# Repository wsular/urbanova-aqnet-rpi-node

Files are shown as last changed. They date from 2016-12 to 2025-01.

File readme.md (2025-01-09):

# Air Quality Network Sensor

## Urbanova

Source code and documentation for an experimental air quality sensor node based
on the Raspberry Pi series and low-cost retail sensors. Measurements are made 
every 10 seconds and recorded to local storage in tab-separated (TSV) files. 
Data are also exported to temporary files for integration with 
[RPi Monitor](https://rpi-experiences.blogspot.com) and `scp`-based scraping 
tools (e.g. the [Itron](https://www.itron.com/na/) Cloud service agent). 

This project is currently being adapted to support multiple platforms, with 
multiple sensor configurations:

| | Original prototype | Next generation |
|:---|:---:|:---:|
| Git branch name | `pi0-usb` | `master` |
| Base platform | [Pi Zero][1] | [Pi 3][2] |
| Operating system | Raspbian Lite (Jessie) | Raspbian Lite (Stretch) |
| Data communications | USB network interface  | Wi-Fi or cellular (2/3G) ([FONA 808][3]) |
| Clock source | RTC ([DS3231][4]) | GPS ([Ultimate GPS][5]) |
| Analog-to-digital converter | n/a | ? (2ch, diff: [ADS1115][10]) |
|-|-|-|-|
| Carbon dioxide conc. (CO<sub>2</sub>) | &check; ([K30][6]) | &check; ([K30][6]) |
| Particulate conc. (PM<sub>1/2.5/10</sub>) | &check; ([OPC-N2][7]) | &check; ([OPC-N2][7])  |
| Ozone conc. (O<sub>3</sub>) | &cross; | ? ([OX-B431][8]) |
| Nitrogen dioxide conc. (NO<sub>2</sub>) | &cross; | ? ([NO2-B43F][9]) |
| Ambient air temp. | &check; ([HTU21DF][11]) | &check; ([BME280][13]) |
| Ambient relative humidity | &check; ([HTU21DF][11]) | &check; ([BME280][13]) |
| Barometric pressure | &check; ([BMP280][12])  | &check; ([BME280][13]) |
| Enclosure (internal) temp. | &check; ([BMP280][12])  | &cross; |
| Location (GPS coordinates) | &cross; | &check; GPS ([Ultimate GPS][5]) |

  [1]: https://www.raspberrypi.org/products/raspberry-pi-zero/
  [2]: https://www.raspberrypi.org/products/raspberry-pi-zero/
  [3]: https://www.adafruit.com/product/2542 "FONA 808"
  [4]: https://www.adafruit.com/product/3013 "DS3231 breakout"
  [5]: https://www.adafruit.com/product/746 "Ultimate GPS"
  [6]: http://senseair.senseair.com/products/oem-modules/k30/ "K30"
  [7]: http://www.alphasense.com/index.php/products/optical-particle-counter/ "OPC-N2"
  [8]: http://www.alphasense.com/index.php/products/ozone-2/
  [9]: http://www.alphasense.com/index.php/products/nitrogen-dioxide-2/
  [10]: https://www.adafruit.com/product/1085 "ADS1115"
  [11]: https://www.adafruit.com/product/1899 "HTU21DF breakout"
  [12]: https://www.adafruit.com/product/2651 "BMP280 breakout"
  [13]: https://www.adafruit.com/product/2652 "BME280 breakout"

### Documentation

* [Assembly notes](doc/hardware.md)
* [Initial setup](doc/software.md)
* [Integration with Itron Cloud](doc/itron.md)

Also, a relevant excerpt from optical particle counter user manual:

> "The accepted international standard definitions of particle mass loadings in
> the air are PM1, PM2.5 and PM10.  These definitions relate to the mass and 
> size of particles that would be inhaled by a typical adult. So, for example,
> PM2.5 is defined as ‘particles which pass through a size-selective inlet with
> a 50% efficiency cut-off at 2.5 μm aerodynamic diameter’.  The 50% cut-off 
> indicates that a proportion of particles of larger than 2.5 μm will be 
> included in PM2.5, the proportion decreasing withincreasing particle size, in
> this case out to approximately 10 μm particles."

### Testing

A few test data sets are available [here](testing/). You can view example code
in the Jupyter notebook "[Validation Testing](testing/Validation%20Testing.ipynb)" 
directly in Github, or to see/interact with the Bokeh plots too, open locally
with Jupyter or [render it](http://nbviewer.jupyter.org/github/wsular/urbanova-aqnet-rpi-node/blob/master/testing/Validation%20Testing.ipynb)
using nbviewer.jupyter.org. 

* Bench test (Dec 4-5, 2016)
* Roof test #1 (Dec 5-6, 2016)
* Roof test #2 (Dec 14, 2016 - Jan 9, 2017)

### License

This work licensed under [The MIT License](http://opensource.org/licenses/mit-license.html).

### References

* Alphasense. *Alphasense User Manual OPC-N2 Optical Particle Counter.*
  Revision Apr 2015. Online: 
  <http://web.archive.org/web/20161203001923/http://staging1.unep.org/uneplive/media/docs/air_quality/aqm_document_v1/Blue%20Print/Components/Microcomputer%20and%20sens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>

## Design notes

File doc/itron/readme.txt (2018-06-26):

# Integration with the Itron Cloud

### Querying for data in real time

The Itron system controller generates and loads an ssh key onto the downstream
air quality sensor node computer during initial device setup. Subsequently,
the Itron controller issues remote shell commands (i.e. `cat`) via ssh to
obtain new measurement values.

Key metrics are summarized in the table below; full descriptions of all metrics
are available in [this Excel&trade; file](data-schema.xlsx).

| Metric description | Units  | Current value file path |
|---|---|---|
| Barometric pressure  | mbar | `/run/aqnet/bmp280/P` |
| Air temperature | &deg;C | `/run/aqnet/bmp280/T` |
| Carbon dioxide (CO<sub>2</sub> mixing ratio | ppmv | `/run/aqnet/k30/CO2` |
| Particulate (PM<sub>1</sub>) concentration | µg/m<sup>3</sup> | `/run/aqnet/opcn2/PM1` |
| Particulate (PM<sub>2.5</sub>) concentration | µg/m<sup>3</sup> |  `/run/aqnet/opcn2/PM2.5` |
| Particulate (PM<sub>10</sub>) concentration  | µg/m<sup>3</sup> |  `/run/aqnet/opcn2/PM10`  |

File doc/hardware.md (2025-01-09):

# Assembly notes

### Urbanova Air Quality Network Sensor Prototype

Some construction and build notes for the deployed prototypes.

## Wiring

We recommend having all hardware connected directly to the Raspberry Pi, 
including power connectors. An expansion board like [this one](https://www.adafruit.com/product/2314)
or [this one](https://www.adafruit.com/product/3203) will greatly simplify 
connecting devices to the I2C bus and power pins. 

> *Through trial-and-error, we determined the Alphasense OPC-N2 aerosol sensor
> exhibits high sensitivity to input voltage and ground differentials between
> its data and power lines. To avoid the dreaded "your firmware could not be 
> detected" error, connect power input and power ground lines directly to the
> Pi Zero's 5V and G rails, respectively.* 
> 
> *The Pi can source up to 1.5A through its GPIO pins, which is sufficient to
> support the OPC-N2 start-up current requirements. Of course, you should use a 
> high quality power supply that can source at least 2A.*

Diagram of wiring connections (open images with [Draw.io](https://www.draw.io/) 
to edit, export as PNG with "include a copy.." to save):

### Pi 0

Wiring diagram for Pi 0

### Pi 3

Wiring diagram for Pi 3

## CAD Drawings

To-scale CAD drawings of environmental sensors for positioning enclosure 
cut-outs and mounting holes. PDFs sized for Letter paper.

* CO2 sensor (K30): [.dxf](diagrams/panel-layout_K30.dxf), [.pdf](diagrams/panel-template_K30.pdf)
* PM sensor (OPC-N2): [.dxf](diagrams/panel-layout_OPC-N2.dxf), [.pdf](diagrams/panel-template_OPC-N2.pdf)
* T/RH sensor (HTU21D): [.dxf](diagrams/panel-layout_HTU21DF.dxf), [.pdf](diagrams/panel-template_HTU21DF.pdf)
* P/T sensor (BMP280): *n/a, mounted inside enclosure*

## Next-gen Unit Construction

> ***Fix me***

## Prototype Construction

Sensors are exposed to ambient conditions through holes in the bottom of the 
enclosure. See *CAD Drawings* above for printable position templates. 

> *The pressure/temperature sensor is located entirely within the enclosure. It
> still represents barometric pressure as the box is not air-tight, but the
> temperature measurement does not reflect ambient conditions.*

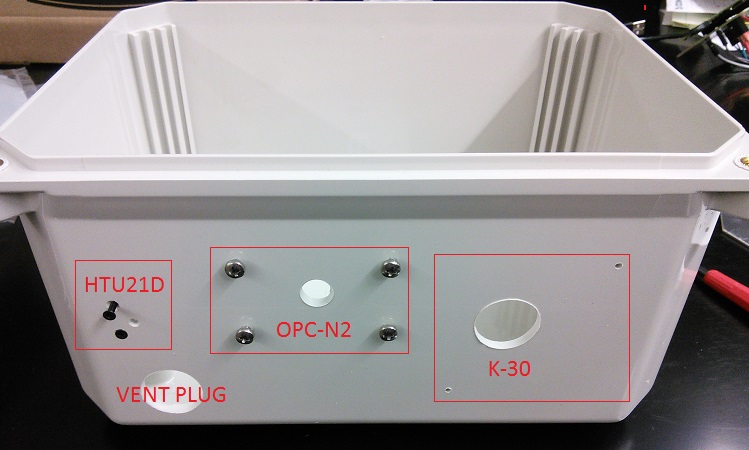
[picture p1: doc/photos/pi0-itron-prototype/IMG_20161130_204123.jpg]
Holes drilled in bottom of enclosure


Rudimentary weatherproofing of the T/RH sensor (HTU21D) is done with hot glue:

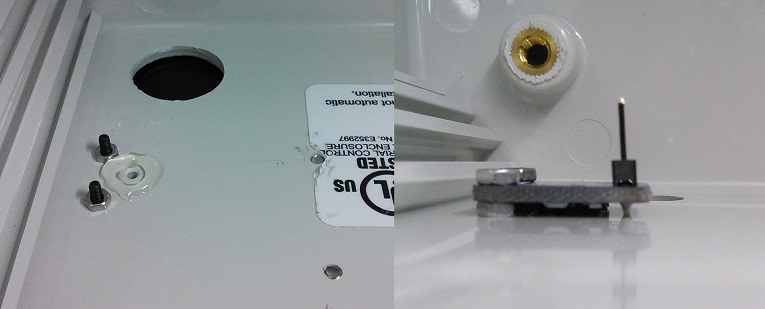
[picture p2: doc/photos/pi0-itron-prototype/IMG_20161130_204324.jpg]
Install details for temp/RH sensor


The aerosol sensor (OPC-N2) has a foam gasket for weather resistance; secure it
using M3 screws (try 5mm length). The CO2 sensor (K30) fits snugly to the 
enclosure on #4-40, 5/16" tall stand-offs:

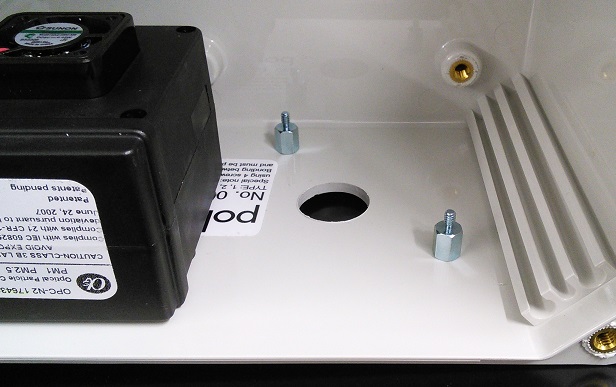
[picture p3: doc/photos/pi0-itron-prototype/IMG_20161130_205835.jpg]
Detail image of OPC-N2 and K30 mounting


Raspberry Pi, pressure/temperature sensor (BMP280) and real-time clock (RTC)
(DS3231) are mounted to the rear panel:

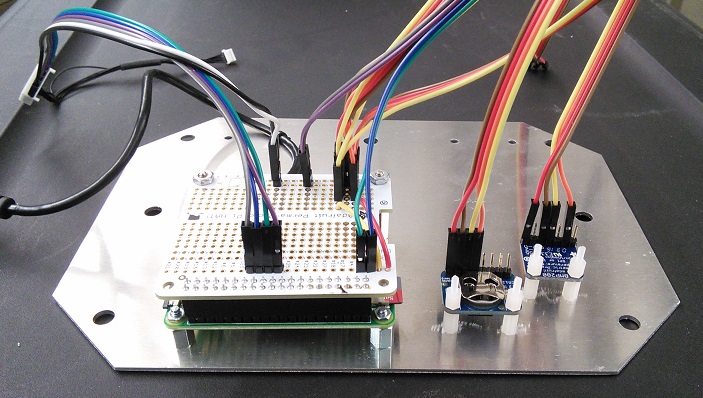
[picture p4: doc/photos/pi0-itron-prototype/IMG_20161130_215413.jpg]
Top down view of internal mounting panel


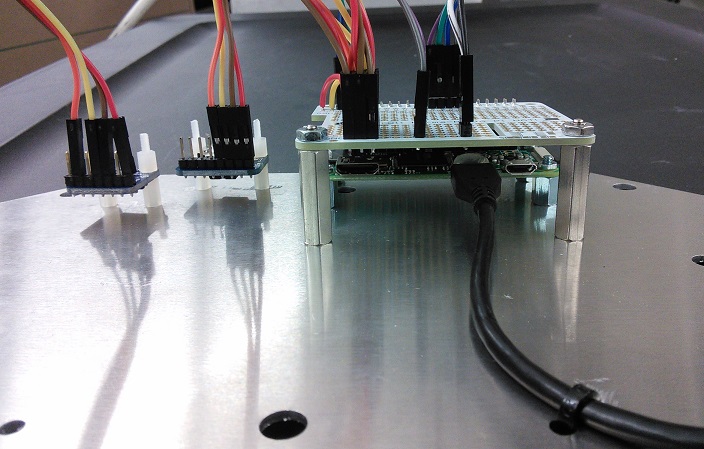
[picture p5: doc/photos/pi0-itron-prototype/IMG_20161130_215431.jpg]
Bottom up view of internal mounting panel


Keep those connectors (all of them!) in place with hot glue:

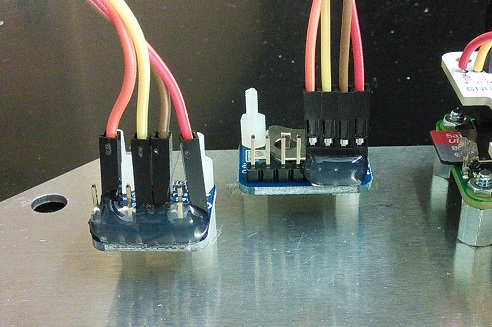
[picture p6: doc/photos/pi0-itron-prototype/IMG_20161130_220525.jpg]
Example of pinning connectors with hot glue


You can improvise stand-offs of any size using long bolts and hex nuts. This
photo also shows a more compact Pi Hat layout with clock and P/T sensor
directly mounted.

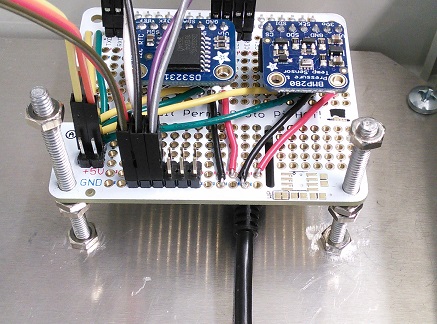
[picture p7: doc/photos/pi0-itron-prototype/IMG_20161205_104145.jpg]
Poor man's stand off


The inside of an assembled package looks like this:

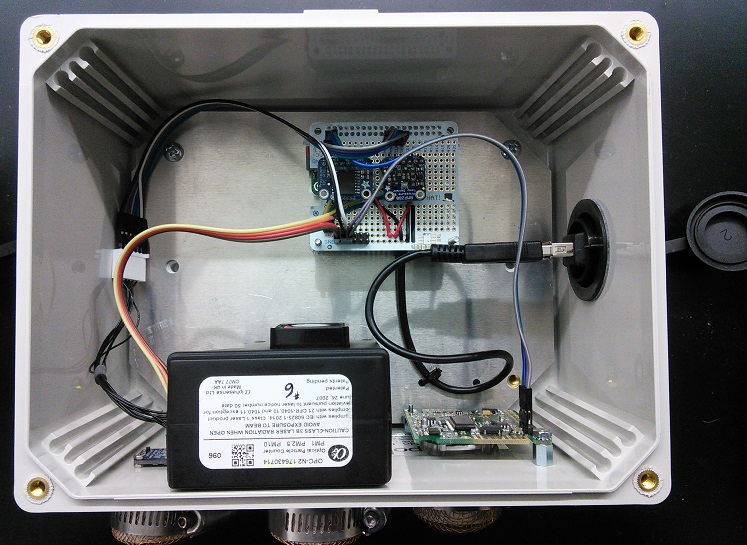
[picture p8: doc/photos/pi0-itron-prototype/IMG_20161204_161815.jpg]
Internal view with all components installed


And the three prototype units looked like this during their initial bench tests
on the Paccar roof Dec 2016-Jan 2017.

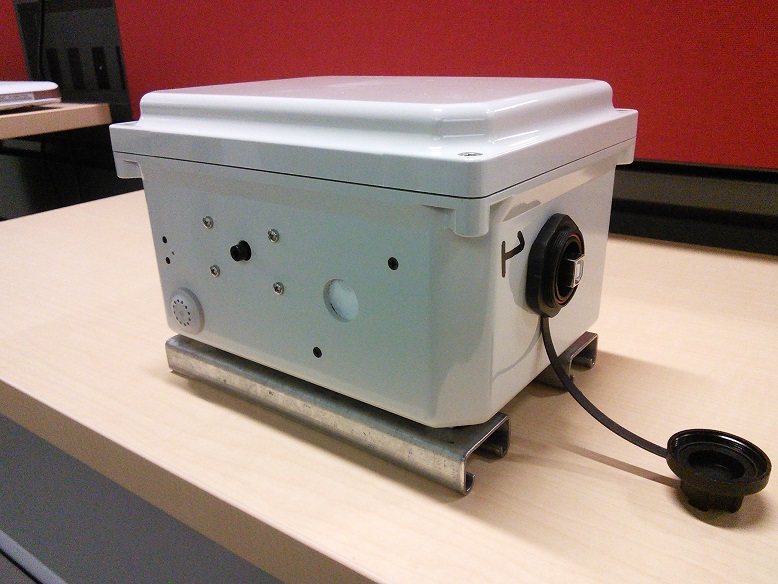
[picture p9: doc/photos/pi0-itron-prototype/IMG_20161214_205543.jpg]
Prototype unit #1


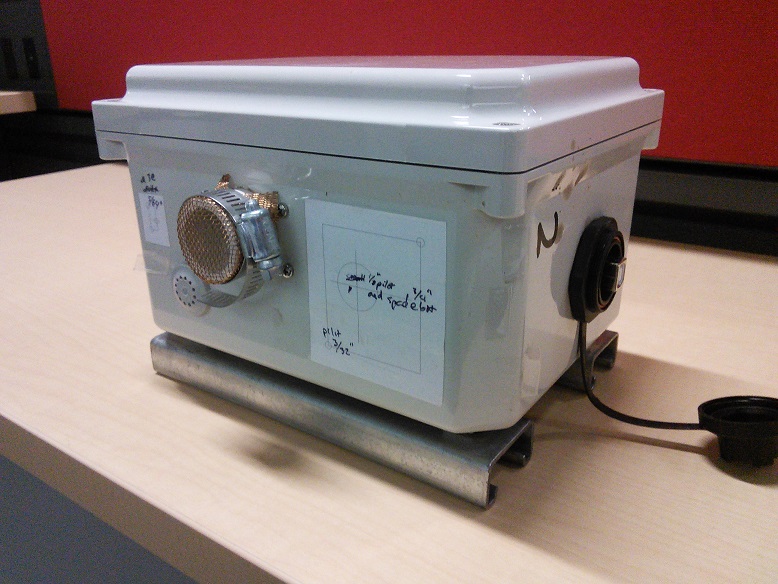
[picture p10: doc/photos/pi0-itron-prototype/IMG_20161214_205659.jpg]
Prototype unit #2


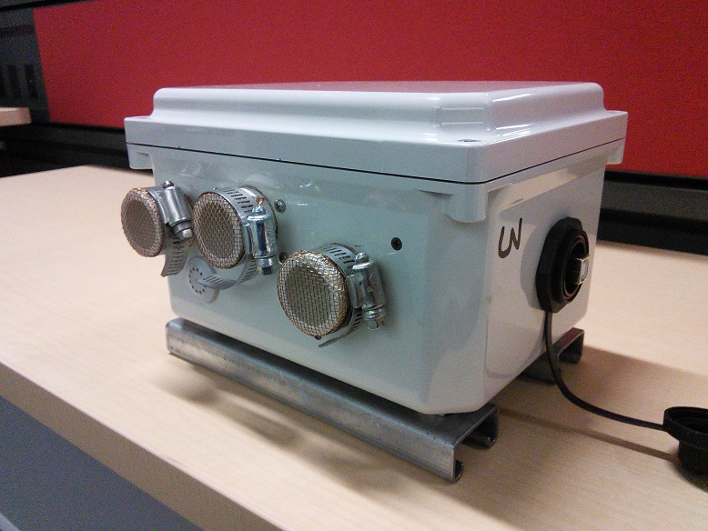
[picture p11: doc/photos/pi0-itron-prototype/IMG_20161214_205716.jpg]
Prototype unit #3


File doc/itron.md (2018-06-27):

# Integration with the Itron Cloud

### Device connections

The prototype AQ node connects to the control unit with a weather-resistant,
standard type A/B USB cord. This cable provides power to the sensor array and
supports communications with the control unit via emulated network interface.

Each prototype AQ node has the static IP address `10.20.0.2/24` and expects a
network gateway with the IP address `10.20.0.1/24`. The control unit is then
configured with the static IP `10.20.0.1/24` (and a local DNS server to proxy
requests from the AQ node). 

### Querying for data in real time

The Itron system controller generates and loads an ssh key onto the downstream
air quality sensor node computer during initial device setup. Subsequently,
the Itron controller issues remote shell commands (i.e. `cat`) via ssh to
obtain new measurement values.

Key metrics are summarized in the table below; full descriptions of all metrics
are available in [this Excel&trade; file](data-schema.xlsx).

| Metric description | Units  | Current value file path |
|---|---|---|
| Barometric pressure  | mbar | `/run/aqnet/bmp280/P` |
| Air temperature | &deg;C | `/run/aqnet/bmp280/T` |
| Carbon dioxide (CO<sub>2</sub> mixing ratio | ppmv | `/run/aqnet/k30/CO2` |
| Particulate (PM<sub>1</sub>) concentration | µg/m<sup>3</sup> | `/run/aqnet/opcn2/PM1` |
| Particulate (PM<sub>2.5</sub>) concentration | µg/m<sup>3</sup> |  `/run/aqnet/opcn2/PM2.5` |
| Particulate (PM<sub>10</sub>) concentration  | µg/m<sup>3</sup> |  `/run/aqnet/opcn2/PM10`  |

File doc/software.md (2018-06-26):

# Install notes

### Urbanova Air Quality Network Sensor Prototype

## O/S Setup

Starting with a clean Raspbian [Jessie Lite](https://www.raspberrypi.org/downloads/) 
(Sep16) install...

1. With `raspi-config`:
    1. Change the password
    2. Set approp locale/kb/tz
    3. ~~Set the hostname~~ Will be set later using Pi's serial number
    4. Enable SPI
    5. Enable I2C
    6. Disable shell on serial port
    7. Enable SSH server (no longer on by default)
    8. Disable wait for network at boot
    9. Advanced > Update
1. Reboot
1. `sudo apt-get dist-upgrade`
1. install basic utilities: `git tmux htop build-essential python-dev python-pip`
    * update *pip* using `sudo pip install --upgrade pip`
1. Setup watchdog service
    1. install `watchdog`
    2. edit `/boot/config.txt` to contain `dtoverlay=watchdog=on`
       [ref](https://github.com/raspberrypi/linux/issues/1285#issuecomment-182264729)
    3. fixup the systemd service file [thanks to](https://kd8twg.net/2015/10/30/raspberry-pi-enabling-watchdog-on-raspbian-jessie/):
       edit `/lib/systemd/system/watchdog.service` to contain:
        ```
        [Install]
        WantedBy=multi-user.target
        ```
    4. edit `/etc/watchdog.conf` to contain
       [ref](https://blog.kmp.or.at/watchdog-for-raspberry-pi/)
        ```
        watchdog-device = /dev/watchdog
        watchdog-timeout = 10
        interval = 2
        max-load-1 = 24
        ```
    5. enable service and start it using sytemctl
    6. finally, test it with a fork bomb: `:(){ :|:& };:`
       the Pi should return a PID number, then hang, then reboot
1. Enable persistent system logs: `sudo mkdir -p /var/log/journal`
   [ref](https://www.digitalocean.com/community/tutorials/how-to-use-journalctl-to-view-and-manipulate-systemd-logs)
1. enable NPT stats: edit `/etc/ntp.conf` to uncomment line starting
    with `statsdir ...`
1. Power down and install hardware. *If you are working on a different Pi, put
   the SD card into the correct unit now.* All hardware should be assembled as
   described in the [Assembly notes](../build/). Once finished, supply power
   and proceed.

## Sensor Software

All hardware must be assembled and attached before proceeding.

1. Enable real-time clock [ref](https://learn.adafruit.com/adding-a-real-time-clock-to-raspberry-pi?view=all)
    1. install: `python-smbus i2c-tools`
    2. edit `/boot/config.txt` to contain `dtoverlay=i2c-rtc,ds3231`
    3. reboot
    4. run `i2cdetect 1` and verify 0x68=`UU`
    5. `sudo apt-get -y remove fake-hwclock`
    6. `sudo update-rc.d -f fake-hwclock remove`
    7. edit `/lib/udev/hwclock-set` to comment out
        ```
        #if [ -e /run/systemd/system ] ; then
        #    exit 0
        #fi
        ```
    8. set clock (check for valid datetime first with `date`):
       `sudo hwclock -w` (read back with `sudo hwclock -D -r`)
1.  Setup for K30 CO2 sensor
    1. install `python-serial`
    2. ~~enable the UART: edit `/boot/config.txt` to contain `enable_uart=1`~~
       * <http://elinux.org/RPi_Serial_Connection>
       * <https://www.raspberrypi.org/forums/viewtopic.php?f=28&t=141195>
       * <https://github.com/raspberrypi/firmware/issues/553#issuecomment-199486644>
       * *this step no longer necessary (?)*
1. Setup for BMP280 T/P sensor
    1. `git clone https://github.com/bastienwirtz/Adafruit_Python_BMP`
    2. `cd Adafruit_Python_BMP && sudo python setup.py install`
1. Setup for HTU21DF RH/T sensor
    1. `git clone https://github.com/raspberrypi/weather-station`
    2. use relative imports to obtain the module
       [ref](http://stackoverflow.com/a/279338/2946116):
        ```
        import sys
        sys.path.append('../weather-station/')
        import HTU21D
        ```
1. [Setup for OPC-N2 sensor](http://py-opc.readthedocs.io/en/latest/)
    1. `sudo pip install spidev py-opc`

## Communication Setup

Follow these steps to enable network communications with the Pi Zero over its
USB on-the-go (OTG) port. 

### On the Pi Zero

1. [Enable Ethernet Gadget mode](https://learn.adafruit.com/turning-your-raspberry-pi-zero-into-a-usb-gadget?view=all)
    1. edit `/boot/config.txt` to contain `dtoverlay=dwc2`
    2. edit `/boot/cmdline.txt` to contain `modules-load=dwc2,g_ether`
       directly after `rootwait`
    3. Reboot
1. ~~Set static IP on device -- add to `/etc/network/interfaces`~~ This step
   superceded by `install.sh`.
    ```
    allow-hotplug usb0
    iface usb0 inet static
        address 10.20.0.2
        netmask 255.255.255.0
        network 10.20.0.0
        broadcast 10.20.0.255
        gateway 10.20.0.1 # upstream computer
    ```

### On other computers

After enabling Ethernet gadget mode, the Pi Zero will appear to be a usb network
adapter to other computers (hosts). It will have a static IP so other hosts can
easily connect using standard TCP/IP protocols like SSH and HTTP. The only
configuration necessary is to ensure your host is on the same subnet:

Assuming the Pi Zero uses static IP `10.20.0.2/24` per above, the host could
select

* IP address: `10.20.0.1`
* IP subnet: `255.255.255.0`

### Internet pass-through

To share internet from another Linux computer (host), use *dnsmasq* per 
[this SE answer](https://raspberrypi.stackexchange.com/a/50073/54372). 

1. On the host computer, identify 
    * the interface with Internet access (assumed to be `eth0` in this example)
    * the interface created by the Pi Zero (`usb0` in this example)
1. On the host computer, assign a static IP to the Pi Zero interface:
    ```
    sudo nano /etc/network/interfaces
    ```
    ```
    allow-hotplug usb0
    iface usb0 inet static
        address 10.11.12.1
        netmask 255.255.255.0
        network 10.11.12.0
        broadcast 10.11.12.255
    ```
1. Install `dnsmasq` and enable it for the Pi Zero interface:
    ```
    sudo nano /etc/dnsmasq.conf
    ```
    ```
    interface=usb0
    listen-address=10.11.12.1
    bind-interfaces
    server=8.8.8.8 # or whatever
    domain-needed
    bogus-priv
    dhcp-range=10.11.12.2,10.11.12.100,1h
    ```
   Then modify the *dnsmasq* service file so it continues running even if the
   network interface is not present:
    ```
    sudo nano /lib/systemd/system/dnsmasq.service
    ````
    ````
    [Service]
    ...
    Restart=always
    RestartSec=30
    ```
1. Enable packet forwarding
    * edit `/etc/sysctl.conf` to enable `net.ipv4.ip_forward=1`
    * to set immediately: `sudo sh -c "echo 1 > /proc/sys/net/ipv4/ip_forward"`
1. Create iptables rules (**NB results not saved after reboot; see ref for more
   details**)
    ```
    sudo iptables -t nat -A POSTROUTING -o eth0 -j MASQUERADE
    sudo iptables -A FORWARD -i usb0 -o eth0 -m state --state RELATED,ESTABLISHED -j ACCEPT
    sudo iptables -A FORWARD -i eth0 -o usb0 -j ACCEPT
    ```

## Nginx Reverse Proxy

For details on the testing configuration which included an Nginx reverse proxy,
[see this Gist](https://gist.github.com/patricktokeeffe/85895534418c9a4aa708cacddf421326).

## RPi-Monitor Integration

For small projects, [RPi-Monitor](https://github.com/XavierBerger/RPi-Monitor)
is a good quick-and-dirty solution that achieves:

* local system monitoring (cpu, disk space, uptime, etc)
* round-robin database storage (rrdtool)
* web interface (no SSH req'd for monitoring)
* plotting (with time zoom)

The documentation is not spectacular, but it's easy to get started
(copied from the debian packaage install docs):

```
sudo apt-key adv --recv-keys --keyserver keyserver.ubuntu.com 2C0D3C0F
sudo wget http://goo.gl/vewCLL -O /etc/apt/sources.list.d/rpimonitor.list
sudo apt-get update
sudo apt-get install rpimonitor
```

Open a web browser and navigate to `http://10.11.12.13:8888`. There should 
be a warning about "Update needed...". Pull updates and enable automatic 
updates to keep current:

```
sudo /etc/init.d/rpimonitor update
sudo /etc/init.d/rpimonitor install_auto_package_status_update
```

Now copy the relevant modified template files into the appropriate folder.

> Hasn't been integrated into the install script yet.

```
sudo cp etc/rpimonitor/* /etc/rpimonitor/
```

## Software TODO

* replace manual log file creation with `logging` or `logbook`
    * even better, store data into database instead of flat files
* use non-blocking timing mechanism
    * replace `sleep` with recursively launched function
    * a threaded helper for each sensor?
* properness
    * ~~turn off OPC-N2 at script exit~~

## For demonstration purposes

Notes from setting up update meeting demo unit.

* Prevent console screen from going blank (b/c there is no way to wake it up)
    * http://superuser.com/a/154388/301363
    * http://raspberrypi.stackexchange.com/a/3714/54372
    * http://unix.stackexchange.com/q/8056/160424
    * https://www.raspberrypi.org/forums/viewtopic.php?f=108&t=133519
* Enable auto login to console
* print messages to terminal associated with HDMI display
  (`/dev/tty1`) instead of script's stdout
* force HDMI output so display occurs even if HDMI cord missing at boot time
  (edit `/boot/config.txt` as approp)
* auto-start at boot using `~/.bashrc`; press ^C after login to
  exit prototype script

> autostart options that don't work well:
>
> * cron @reboot (maybe worth retrying)
> * .bashrc (starts for every shell session)
> * /etc/rc.local (no errors, no output)
> * systemd service (can uncapture stdout but requires restart after
>   boot to see output; oddly, can see output in boot messages but
>   not once login presented?)

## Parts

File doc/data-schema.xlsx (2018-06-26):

Urbanova WSU Air Quality Node prototypes
Metric label | Units | Long units | File path | Post-processing, if required | Metric Description
Barometric pressure | mb | millibar | /run/aqnet/bmp280/P |  | Instantaneous value up to 10 seconds old
Enclosure temperature | degC | degrees Celsius | /run/aqnet/bmp280/T |  | Instantaneous value up to 10 seconds old
Air temperature | degC | degrees Celsius | /run/aqnet/htu21d/T |  | Instantaneous value up to 10 seconds old
CO2 concentration | ppmv | parts per million by volume | /run/aqnet/htu21d/RH |  | Instantaneous value up to 10 seconds old
Relative humidity | pct | percent | /run/aqnet/k30/CO2 |  | Instantaneous value up to 10 seconds old
Particle counts, bin 0 | #/mL | counts per milliliter | /run/aqnet/opcn2/Bin_0 |  | Mean value over OPC-N2 sampling period
Particle counts, bin 1 | #/mL | counts per milliliter | /run/aqnet/opcn2/Bin_1 |  | Mean value over OPC-N2 sampling period
Particle counts, bin 2 | #/mL | counts per milliliter | /run/aqnet/opcn2/Bin_2 |  | Mean value over OPC-N2 sampling period
Particle counts, bin 3 | #/mL | counts per milliliter | /run/aqnet/opcn2/Bin_3 |  | Mean value over OPC-N2 sampling period
Particle counts, bin 4 | #/mL | counts per milliliter | /run/aqnet/opcn2/Bin_4 |  | Mean value over OPC-N2 sampling period
Particle counts, bin 5 | #/mL | counts per milliliter | /run/aqnet/opcn2/Bin_5 |  | Mean value over OPC-N2 sampling period
Particle counts, bin 6 | #/mL | counts per milliliter | /run/aqnet/opcn2/Bin_6 |  | Mean value over OPC-N2 sampling period
Particle counts, bin 7 | #/mL | counts per milliliter | /run/aqnet/opcn2/Bin_7 |  | Mean value over OPC-N2 sampling period
Particle counts, bin 8 | #/mL | counts per milliliter | /run/aqnet/opcn2/Bin_8 |  | Mean value over OPC-N2 sampling period
Particle counts, bin 9 | #/mL | counts per milliliter | /run/aqnet/opcn2/Bin_9 |  | Mean value over OPC-N2 sampling period
Particle counts, bin 10 | #/mL | counts per milliliter | /run/aqnet/opcn2/Bin_10 |  | Mean value over OPC-N2 sampling period
Particle counts, bin 11 | #/mL | counts per milliliter | /run/aqnet/opcn2/Bin_11 |  | Mean value over OPC-N2 sampling period
Particle counts, bin 12 | #/mL | counts per milliliter | /run/aqnet/opcn2/Bin_12 |  | Mean value over OPC-N2 sampling period
Particle counts, bin 13 | #/mL | counts per milliliter | /run/aqnet/opcn2/Bin_13 |  | Mean value over OPC-N2 sampling period
Particle counts, bin 14 | #/mL | counts per milliliter | /run/aqnet/opcn2/Bin_14 |  | Mean value over OPC-N2 sampling period
Particle counts, bin 15 | #/mL | counts per milliliter | /run/aqnet/opcn2/Bin_15 |  | Mean value over OPC-N2 sampling period
Particle MToF, bin 1 | us | microseconds | /run/aqnet/opcn2/Bin1_MToF |  | Mean value over OPC-N2 sampling period
Particle MToF, bin 3 | us | microseconds | /run/aqnet/opcn2/Bin3_MToF |  | Mean value over OPC-N2 sampling period
Particle MToF, bin 5 | us | microseconds | /run/aqnet/opcn2/Bin5_MToF |  | Mean value over OPC-N2 sampling period
Particle MToF, bin 7 | us | microseconds | /run/aqnet/opcn2/Bin7_MToF |  | Mean value over OPC-N2 sampling period
PM1 concentration | ug/m^3 | micrograms per cubic meter | /run/aqnet/opcn2/PM1 |  | Mean value over OPC-N2 sampling period
PM2.5 concentration | ug/m^3 | micrograms per cubic meter | /run/aqnet/opcn2/PM2.5 |  | Mean value over OPC-N2 sampling period
PM10 concentration | ug/m^3 | micrograms per cubic meter | /run/aqnet/opcn2/PM10 |  | Mean value over OPC-N2 sampling period
OPC-N2 sampling period | s | seconds | /run/aqnet/opcn2/Sampling_Period |  | Instantaneous value up to 10 seconds old
OPC-N2 sampling rate | mL/s | milliliters per second | /run/aqnet/opcn2/SFR |  | Mean value over OPC-N2 sampling period
Pi uptime | s | seconds | /proc/uptime | cut -d ' ' -f1 | Instantaneous value at time of Reading
PI Load average, 1-min | pct | percent | /proc/loadavg | cut -d ' ' -f1 | Instantaneous value at time of Reading
Pi Memory Available | kB | kilobytes | /proc/meminfo | awk '/MemFree:/ {print $2/1024}' | Instantaneous value at time of Reading
Pi Disk Available | kB | kilobytes |  |  | Instantaneous value at time of Reading
not tracked |  |  | /run/aqnet/opcn2/Checksum
not tracked |  |  | /run/aqnet/opcn2/Pressure
not tracked |  |  | /run/aqnet/opcn2/Temperature

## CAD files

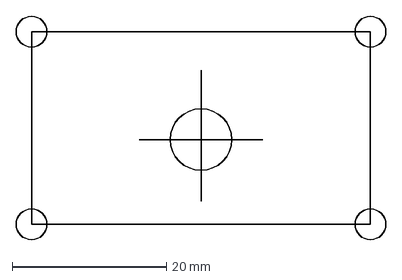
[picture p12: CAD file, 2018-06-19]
doc/diagrams/panel-layout_OPC-N2.dxf
48.0 x 29.0 mm

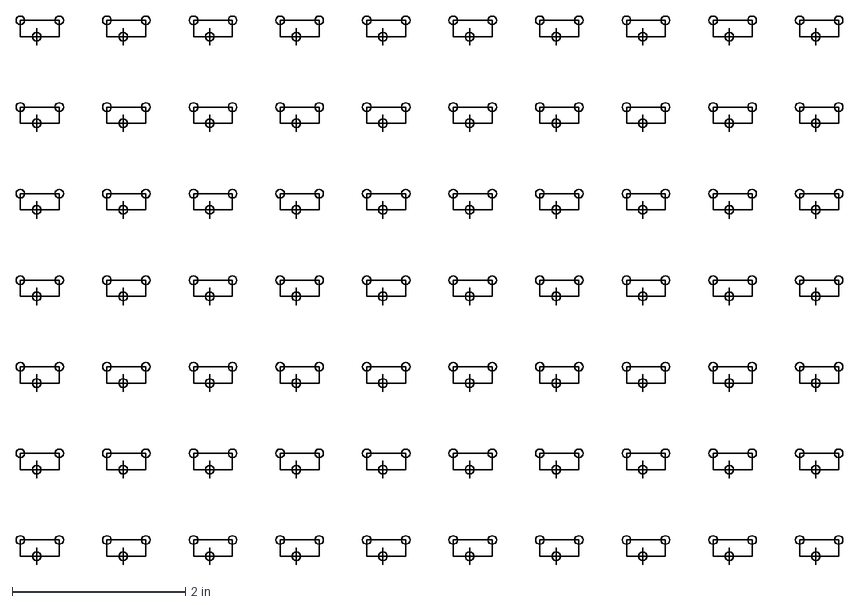
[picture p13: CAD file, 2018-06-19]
doc/diagrams/panel-layout_HTU21DF.dxf
9.55 x 6.34 in

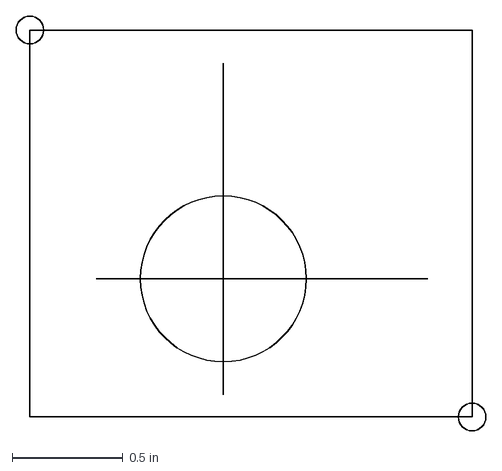
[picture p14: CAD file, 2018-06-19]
doc/diagrams/panel-layout_K30.dxf
2.12 x 1.88 in

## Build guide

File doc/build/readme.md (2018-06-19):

# Assembly notes

### Urbanova Air Quality Network Sensor Prototype

Some construction and build notes for the deployed prototypes.

## Wiring

We recommend having all hardware connected directly to the Raspberry Pi, 
including power connectors. An expansion board like [this one](https://www.adafruit.com/product/2314)
or [this one](https://www.adafruit.com/product/3203) will greatly simplify 
connecting devices to the I2C bus and power pins. 

> *Through trial-and-error, we determined the Alphasense OPC-N2 aerosol sensor
> exhibits high sensitivity to input voltage and ground differentials between
> its data and power lines. To avoid the dreaded "your firmware could not be 
> detected" error, connect power input and power ground lines directly to the
> Pi Zero's 5V and G rails, respectively.* 
> 
> *The Pi can source up to 1.5A through its GPIO pins, which is sufficient to
> support the OPC-N2 start-up current requirements. Of course, you should use a 
> high quality power supply that can source at least 2A.*

Diagram of wiring connections (.png is embedded with [Draw.io](https://www.draw.io/) 
xml file):

Wiring diagram

## CAD Drawings

To-scale CAD drawings of environmental sensors for positioning enclosure 
cut-outs and mounting holes. PDFs sized for Letter paper.

* CO2 sensor (K30): [.dxf](panel-layout_K30.dxf), [.pdf](panel-template_K30.pdf)
* PM sensor (OPC-N2): [.dxf](panel-layout_OPC-N2.dxf), [.pdf](panel-template_OPC-N2.pdf)
* T/RH sensor (HTU21D): [.dxf](panel-layout_HTU21DF.dxf), [.pdf](panel-template_HTU21DF.pdf)
* P/T sensor (BMP280): *n/a, mounted inside enclosure*

## Construction

Sensors are exposed to ambient conditions through holes in the bottom of the 
enclosure. See *CAD Drawings* above for printable position templates. 

> *The pressure/temperature sensor is located entirely within the enclosure. It
> still represents barometric pressure as the box is not air-tight, but the
> temperature measurement does not reflect ambient conditions.*

Holes drilled in bottom of enclosure

Rudimentary weatherproofing of the T/RH sensor (HTU21D) is done with hot glue:

Install details for temp/RH sensor

The aerosol sensor (OPC-N2) has a foam gasket for weather resistance; secure it
using M3 screws (try 5mm length). The CO2 sensor (K30) fits snugly to the 
enclosure on #4-40, 5/16" tall stand-offs:

Detail image of OPC-N2 and K30 mounting

Raspberry Pi, pressure/temperature sensor (BMP280) and real-time clock (RTC)
(DS3231) are mounted to the rear panel:

Top down view of internal mounting panel

Bottom up view of internal mounting panel

Keep those connectors (all of them!) in place with hot glue:

Example of pinning connectors with hot glue

You can improvise stand-offs of any size using long bolts and hex nuts. This
photo also shows a more compact Pi Hat layout with clock and P/T sensor
directly mounted.

Poor man's stand off

The inside of an assembled package looks like this:

Internal view with all components installed

And the three prototype units looked like this during their initial bench tests
on the Paccar roof Dec 2016-Jan 2017.

Prototype unit #1

Prototype unit #2

Prototype unit #3

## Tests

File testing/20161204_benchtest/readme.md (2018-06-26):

# Bench Test #1

### Urbanova Air Quality Network Sensor Prototype

Prototyping data set collected at various locations (see notes below). 

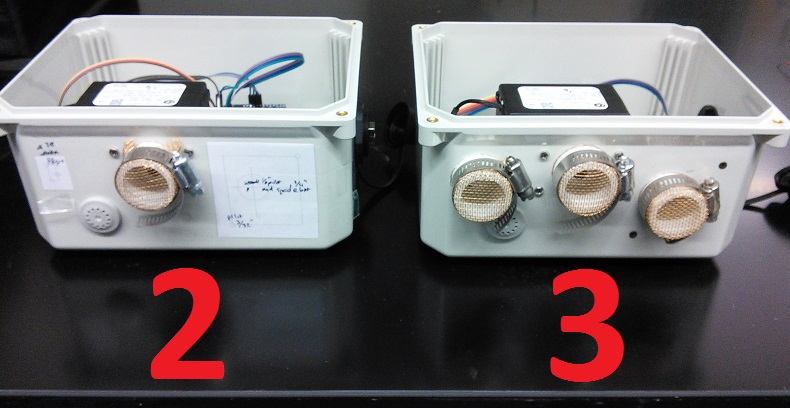
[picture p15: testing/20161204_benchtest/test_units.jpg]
Photo of test units


## 2016-12-04 Su

**~1730**
Both units fully assembled, powered on via usb battery pack. Unit #2 has only
PM sensor exposed, unit #3 has CO2/RH/PM sensors exposed.

**~1745 to 1755**
Travel from lab to home by car. Leave outside door threshold in laundry room.
Both units are in banker box with sensors facing up.

**1810**
Bring the box into my old, non-ventilated 480 s.f. apartment.

**1830**
Leave to store with with box in car

**1834 to 1845**
Parked, then leave to restauraunt.

**~1850 to 1907** 
Parked, then leave to home

**~1915**
Brought inside home

**0050**
Move to laundry room with window fully open

**0215**
Bring units inside

**0225**
Retrieve data from #3 (most sensors exposed) &rarr; det. still running old T/RH
logger script, reinstall everything @ 2:44

**0250**
Connect to #2 (only OPC exposed), done by 3:00

**0310 to 0320**
Car ride to work

**0325**
Left on building roof

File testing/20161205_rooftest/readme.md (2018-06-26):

# Roof Test #1

### Urbanova Air Quality Network Sensor Prototype

First outdoor test data set. Data quality is enhanced by simultaneous carbon
dioxide (CO<sub>2</sub>) measurements made by research-grade gas analyzer
([LI-840A; LICOR Biosciences](https://www.licor.com/env/products/gas_analysis/LI-840A/)).

* Unit 2 has CO2 sensor mounted internally and relies on aerosol sensor to
  provide fresh ambient sample
* Unit 3 exposes the CO2 sensor to ambient conditions through the enclosure wall

## Photos

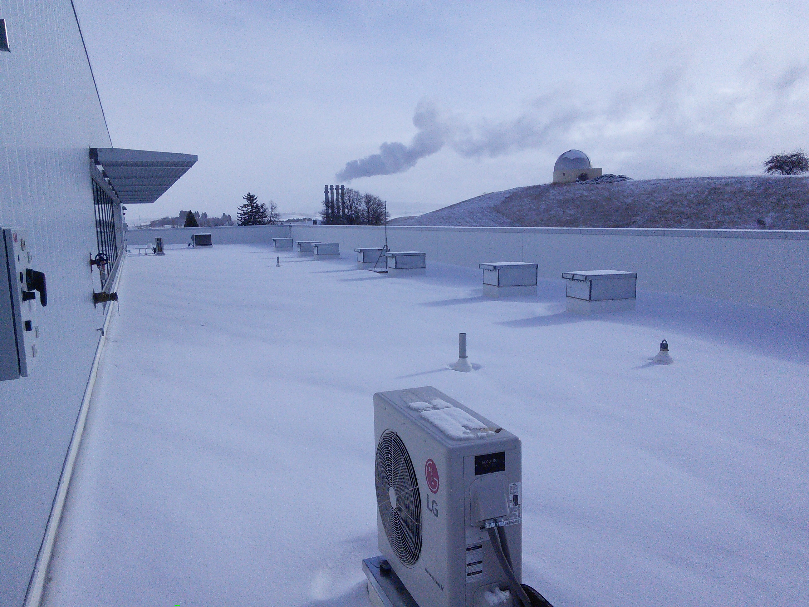
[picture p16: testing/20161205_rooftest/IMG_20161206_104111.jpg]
Rooftop, looking almost east


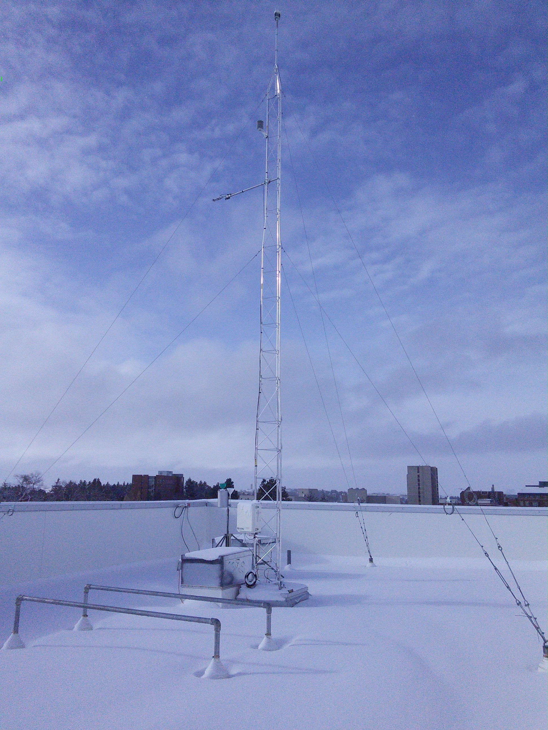
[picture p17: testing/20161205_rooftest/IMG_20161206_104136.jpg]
Rooftop, looking almost west


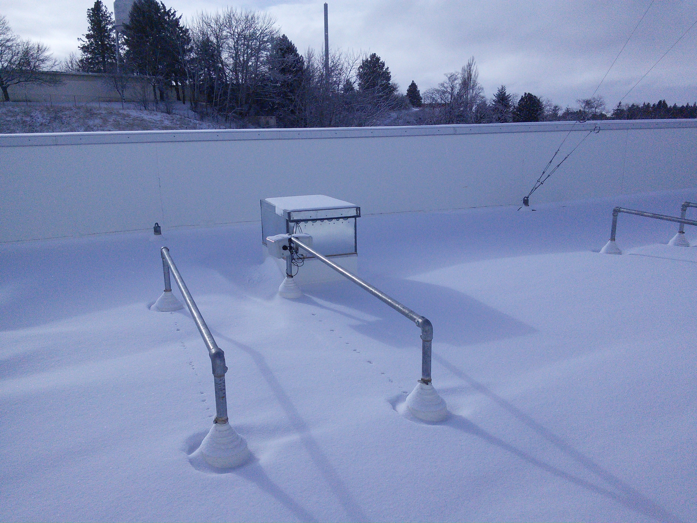
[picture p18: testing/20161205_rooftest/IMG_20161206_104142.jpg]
Test units on rooftop


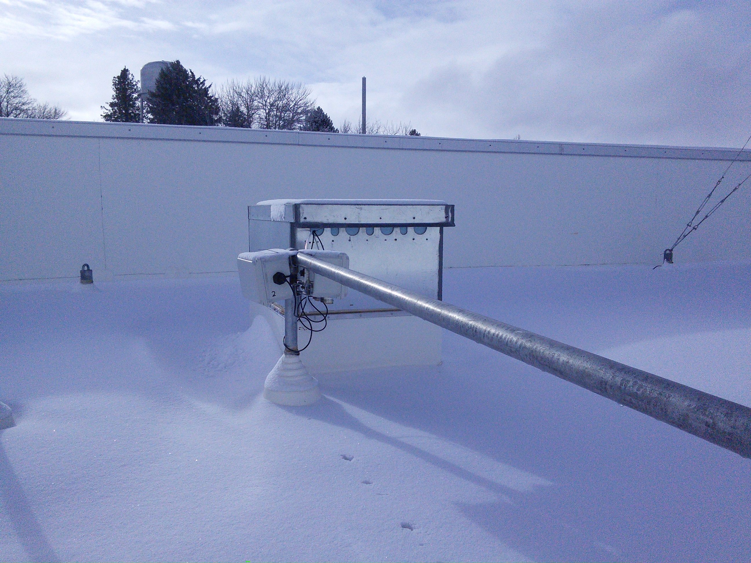
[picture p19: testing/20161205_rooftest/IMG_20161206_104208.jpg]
Test units on rooftop


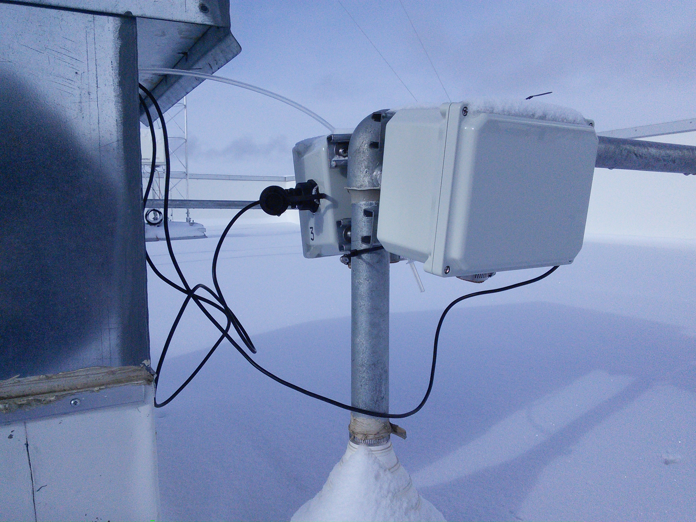
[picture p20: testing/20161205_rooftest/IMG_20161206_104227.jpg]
Test units on rooftop


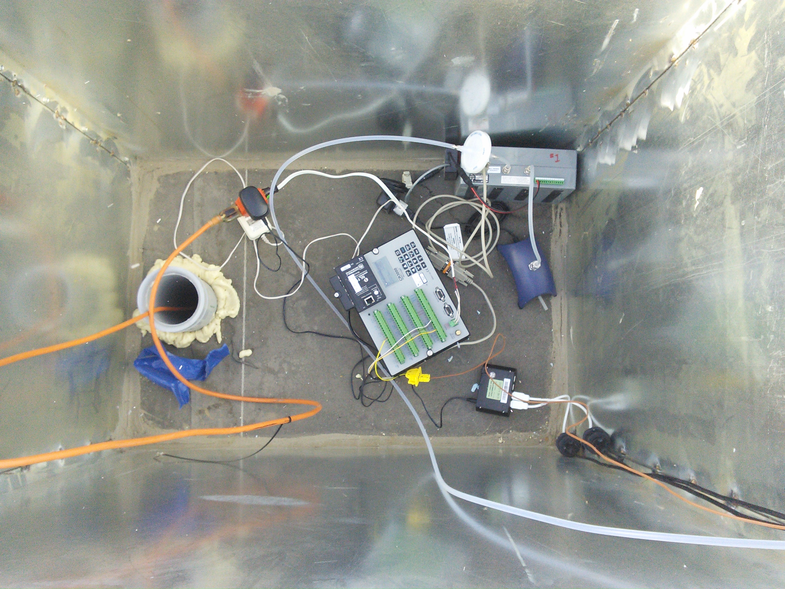
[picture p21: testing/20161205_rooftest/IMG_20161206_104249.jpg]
Supporting equipment


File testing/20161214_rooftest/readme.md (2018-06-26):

# Roof Test #2

### Urbanova Air Quality Network Sensor Prototype

A more complete outdoor test data set with measurements of:

* carbon dioxide (CO<sub>2</sub>) via [LI-840A (LICOR Biosciences)](https://www.licor.com/env/products/gas_analysis/LI-840A/)
* fine aerosols (PM<sub>2.5</sub>) via [DustTrak II (TSI Inc)](http://www.tsi.com/DUSTTRAK-II-Aerosol-Monitor-8530/)
* coarse aerosols (PM<sub>10</sub>) via DustTrak II (TSI Inc)
* weather conditions (T/P/RH/WS/WD) via [150WX (Airmar Technologies)](http://www.airmartechnology.com/weather-description.html?id=155)

> *N.B. The prototype PM, CO<sub>2</sub> and weather data sets are committed as
.zip files to limit overall repository size.*

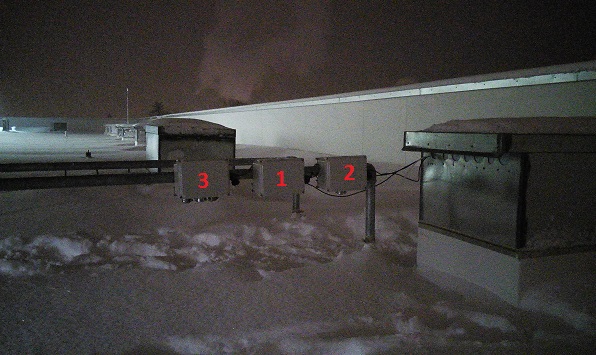
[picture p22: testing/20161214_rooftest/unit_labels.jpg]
Test units with labels


## Photos

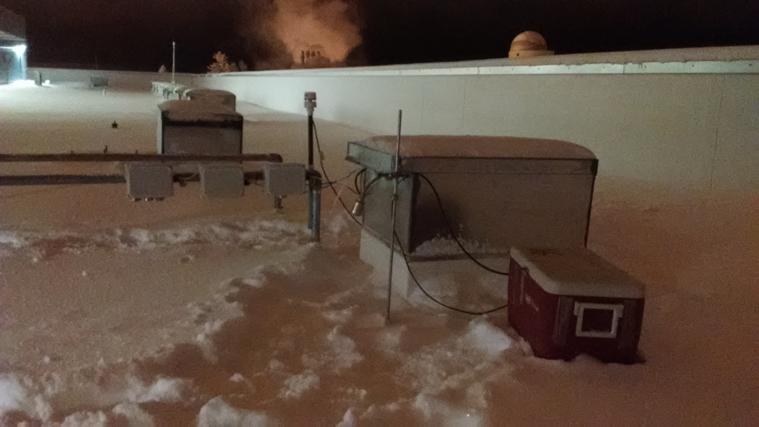
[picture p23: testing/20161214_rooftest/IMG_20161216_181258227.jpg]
Setup photo


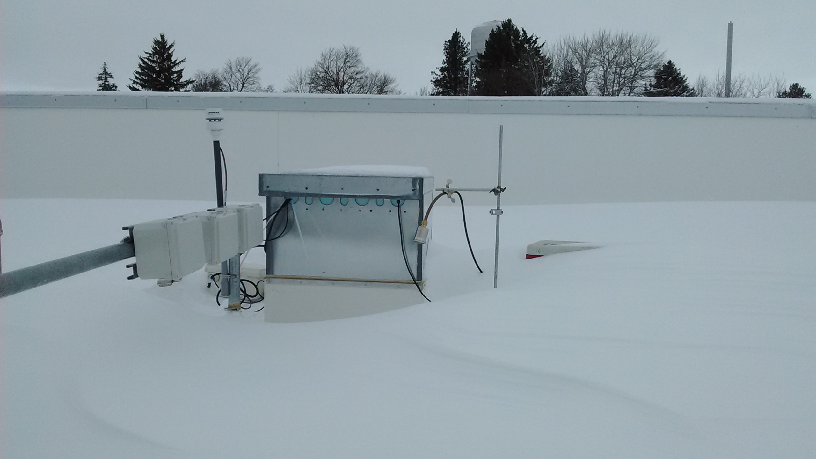
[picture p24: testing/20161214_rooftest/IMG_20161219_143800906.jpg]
Operating photo, before digging out


Operating photo, after digging out

Another operating photo

## Other Files

These images are included because they were part of the data access framework
[described in this Gist](https://gist.github.com/patricktokeeffe/85895534418c9a4aa708cacddf421326)

Unit 1

Unit 2

Unit 3

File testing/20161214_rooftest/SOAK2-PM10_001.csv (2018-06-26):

Instrument Name | DustTrak II
Model Number | 8530
Serial Number | 8530150710
Firmware Version | 3.4
Calibration Date | 2015/02/12
Test Name | SOAK2-PM10_001
Test Start Time | 13:56:57
Test Start Date | 2016/12/15
Test Length [D:H:M] | 7:0:0
Test Interval [M:S] | 0:10
Mass Average [mg/m3] | 0.005
Mass Minimum [mg/m3] | 0.000
Mass Maximum [mg/m3] | 0.065
Mass TWA [mg/m3] | 0.006
Photometric User Cal | 0.38
Flow User Cal | 0.00
Errors
Number of Samples | 60480
Elapsed Time [s] | Mass [mg/m3] | Alarms | Errors
10 | 0.011
20 | 0.006
30 | 0.008
40 | 0.007
50 | 0.006
60 | 0.006
70 | 0.006
80 | 0.006
90 | 0.006
100 | 0.005
110 | 0.005
120 | 0.005
130 | 0.005
140 | 0.005
150 | 0.005
160 | 0.005
170 | 0.004
180 | 0.005
190 | 0.005
200 | 0.005
210 | 0.005
220 | 0.005
230 | 0.005
240 | 0.005
250 | 0.005
260 | 0.005
270 | 0.005
280 | 0.005
290 | 0.005
300 | 0.005
310 | 0.005
320 | 0.005
330 | 0.006
340 | 0.007
350 | 0.005
360 | 0.005
370 | 0.005
380 | 0.005
390 | 0.006
400 | 0.005
410 | 0.005
420 | 0.005
430 | 0.005
440 | 0.005
450 | 0.004
460 | 0.004
470 | 0.005
480 | 0.005
490 | 0.005
500 | 0.005
510 | 0.005
520 | 0.005
530 | 0.005
540 | 0.005
550 | 0.005
560 | 0.005
570 | 0.005
580 | 0.005
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

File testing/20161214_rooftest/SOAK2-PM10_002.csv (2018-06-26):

Instrument Name | DustTrak II
Model Number | 8530
Serial Number | 8530150710
Firmware Version | 3.4
Calibration Date | 2015/02/12
Test Name | SOAK2-PM10_001
Test Start Time | 17:32:26
Test Start Date | 2016/12/22
Test Length [D:H:M] | 5:17:59
Test Interval [M:S] | 0:10
Mass Average [mg/m3] | 0.003
Mass Minimum [mg/m3] | 0.000
Mass Maximum [mg/m3] | 0.031
Mass TWA [mg/m3] | 0.002
Photometric User Cal | 0.38
Flow User Cal | 0.00
Errors
Number of Samples | 49676
Elapsed Time [s] | Mass [mg/m3] | Alarms | Errors
10 | 0.002
20 | 0.002
30 | 0.002
40 | 0.003
50 | 0.002
60 | 0.002
70 | 0.002
80 | 0.002
90 | 0.002
100 | 0.002
110 | 0.002
120 | 0.002
130 | 0.002
140 | 0.002
150 | 0.002
160 | 0.002
170 | 0.002
180 | 0.002
190 | 0.002
200 | 0.002
210 | 0.002
220 | 0.002
230 | 0.002
240 | 0.002
250 | 0.002
260 | 0.002
270 | 0.002
280 | 0.002
290 | 0.002
300 | 0.002
310 | 0.002
320 | 0.002
330 | 0.002
340 | 0.002
350 | 0.002
360 | 0.002
370 | 0.002
380 | 0.002
390 | 0.002
400 | 0.002
410 | 0.002
420 | 0.002
430 | 0.002
440 | 0.002
450 | 0.002
460 | 0.002
470 | 0.002
480 | 0.002
490 | 0.002
500 | 0.002
510 | 0.002
520 | 0.002
530 | 0.002
540 | 0.002
550 | 0.002
560 | 0.002
570 | 0.002
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

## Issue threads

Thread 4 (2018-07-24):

Integrate GPS sensor

patricktokeeffe, 2018-07-24:
Integrate the Ultimate GPS v3 breakout board as a GPS sensor/real-time clock (RTC) module:

* [x] document wiring
  * [ ] investigate adding PPS for microsecond support
  * [ ] possibly swap with K30 for Pi's hardware uart (to avoid USB errors during boot)
  * [ ] add light pipe or secondary LED to for external status indicator?
* [ ] enable as RTC
  * [ ] make Pi use for hardware clock (reason to use hardware UART?)
  * [ ] tie into `ntpd` systemd service
  * [ ] verify battery back-up operational
  * [ ] enable ntp statistics
* GPS data outputs
  * [ ] locally republish NMEA0183 data using [kplex](http://catb.org/gpsd/)? [gpsd](http://catb.org/gpsd/)?
  * [ ] log all NMEA0183 sentences to disk? with rotation limits?
  * [ ] add position logging to AQ data service
  * [ ] report current status (and possibly statistics) to local RPi Monitor instance

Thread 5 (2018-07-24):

Integrate Alphasense gas sensors

patricktokeeffe, 2018-07-24:
Integrate Alphasense ozone (O3, OX-B431) and nitric oxide (NO2,NO2-B43F) trace gas sensors, plus their analog-to-digital converter (ADS1115):

* wiring & setup
  * [ ] evaluate whether [PowerBoost 1000](https://www.adafruit.com/product/2465) has sufficiently stable 5V output to power "ISB" breakout boards
  * [ ] connect ADC and gas sensors in differential configuration
  * [ ] program the ADC PGA for optimal operation with sensors reporting ranges, etc
  * [ ] determine if ADC must be on Pi3 hat, or if header wire is acceptable for I2C data
* software
  * [ ] check alphasense docs for advanced data options
  * [ ] add concentration logging to AQ data service
  * [ ] add gas concentrations to local RPi Monitor instance
* quality control
  * ?

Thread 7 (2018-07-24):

Keep separate humidity probe?

patricktokeeffe, 2018-07-24:
Replacing the BMP180/BMP280 (T/P) with BME280 (T/P/RH) makes relative humidity from the HTU21D-F (T/RH) redundant. However, the BMP280 requires ambient exposure and moving that sensor from enclosure interior to an ambient position removes the enclosure internal temperature measurement.

Instead of removing the HTU21D-F, it could be retained and used to monitor the enclosure environmental status (i.e. temperature/humidity) versus ambient.

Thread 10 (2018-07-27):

Improve local storage to TSV

patricktokeeffe, 2018-07-27:
Can we transition the TSV files to psuedo-TOA5? (relocated from comment on #9)

### Campbell Scientific TOA5

* comma-separated values
* multi-line header

----

*Excerpted from CR1000 User Manual, rev 2/18, section 7.6.3.11.1:*

**Line 1: Environment Line**

| Field | Description | *Proposed value for Urbanova AQ node* |
|---|---|---|
| 1 | **TOA5** | **TOA5** (part of standard) |
| 2 | Station name | name/ID of assembled sensor package?  |
| 3 | Datalogger model | lookup values corresponding to specific hardware configurations? |
| 4 | Datalogger serial number | serial number of just raspberry Pi? of entire assembled AQ node? |
| 5 | Datalogger OS version | Git tag/hash of installed software version |
| 6 | Datalogger program name | name of DAQ script? |
| 7 | Dataloger program signature | blank/not used? other sentinel to emphasize not a real TOA5 file? use for Git tag/hash instead? |
| 8 | Table name | **?** |

**Line 2: Header**

This line consists of comma-delimited strings that identify the name of individual fields as given in the datalogger program.

**Line 3: Units**

This line identifies engineering units for that field of data, as declared at the beginning of the CRBasic program.

**Line 4: Aggregation**

The fourth line reports abbreviations of the data process used to produce the field of data. See table 20 within user manual section 7.6.3.17 (rev 2/18).

**All additional lines**

Subsequent lines are observed data and associated record keeping. The first field being a timestamp, and the second being the record (sequential) number.

### Notes

* station name
  * sensor packages record lat/long... but that's not a name. Monitoring locations need names and multiple units can be installed at any one location so that name cannot be the same as the sensor unit.
  * if station represents assembled package, then logger serial can represent the Pi specifically (or whatever hardware is doing DAQ)

vonw, 2018-07-29:
More...

Field 6: Sure. Name of DAQ script works for me.

Field 7: I don't understand what this is, but I'll take your recommendation for what it should be.

Field 8: I'm not sure what this is. I see the "table" as the "data", and this is adequately described by the header lines 2, 3, and 4. But again, I'll take your recommendation for what this should be, if anything.

vonw, 2018-07-29:
Thanks again, Patrick, for defining this. Nice work!

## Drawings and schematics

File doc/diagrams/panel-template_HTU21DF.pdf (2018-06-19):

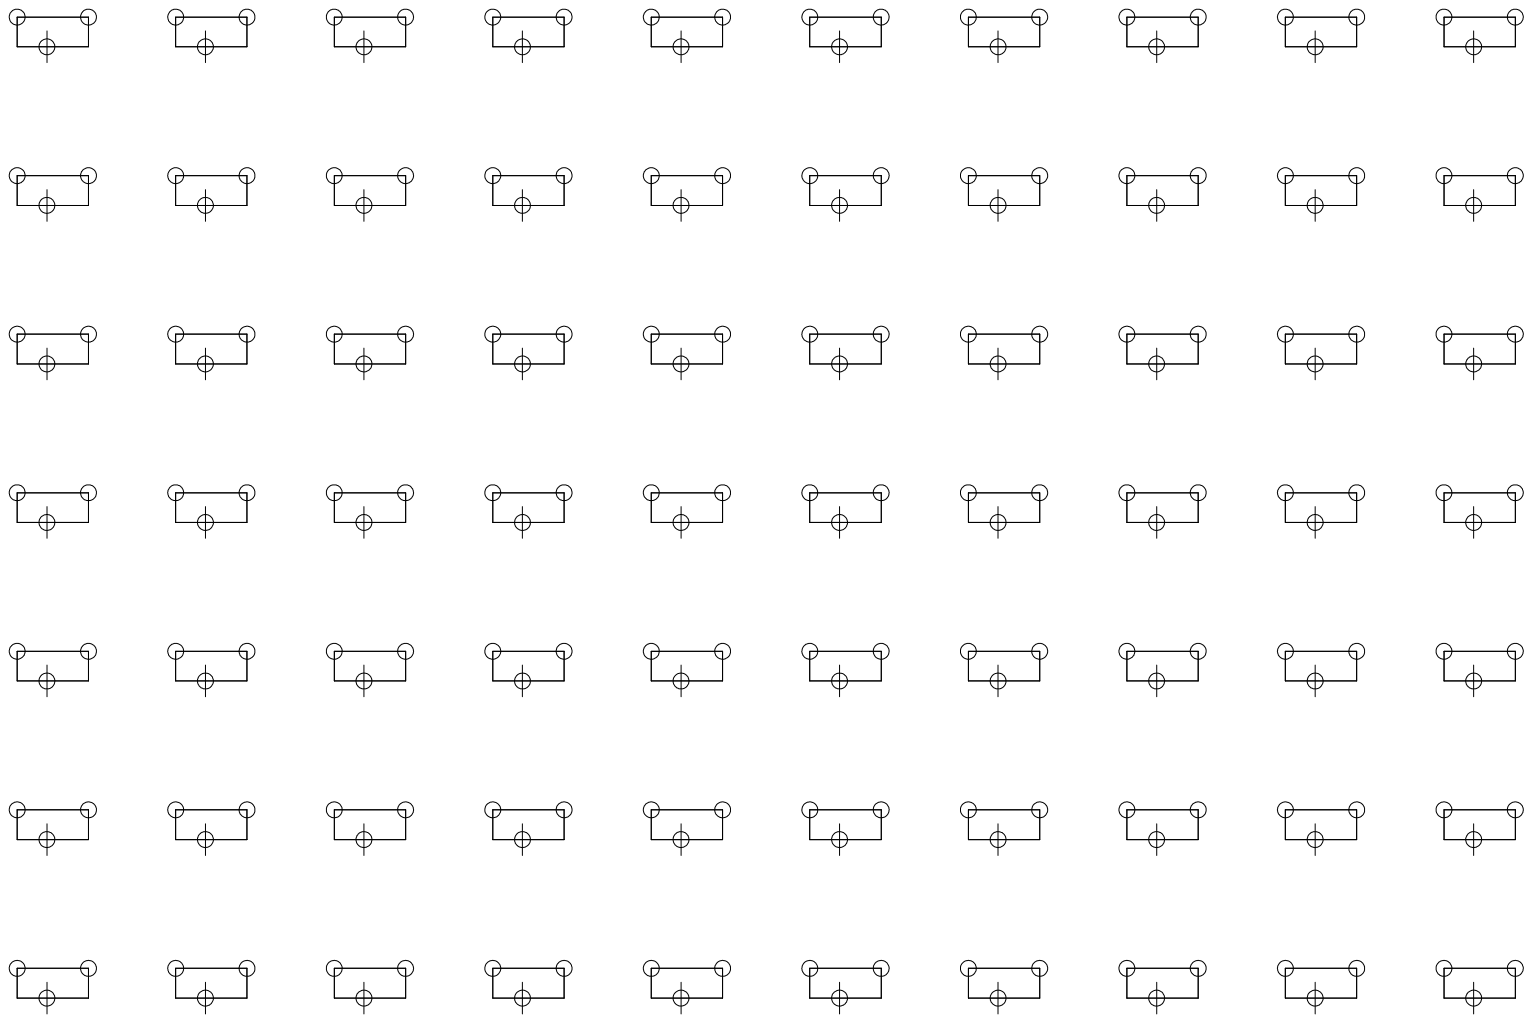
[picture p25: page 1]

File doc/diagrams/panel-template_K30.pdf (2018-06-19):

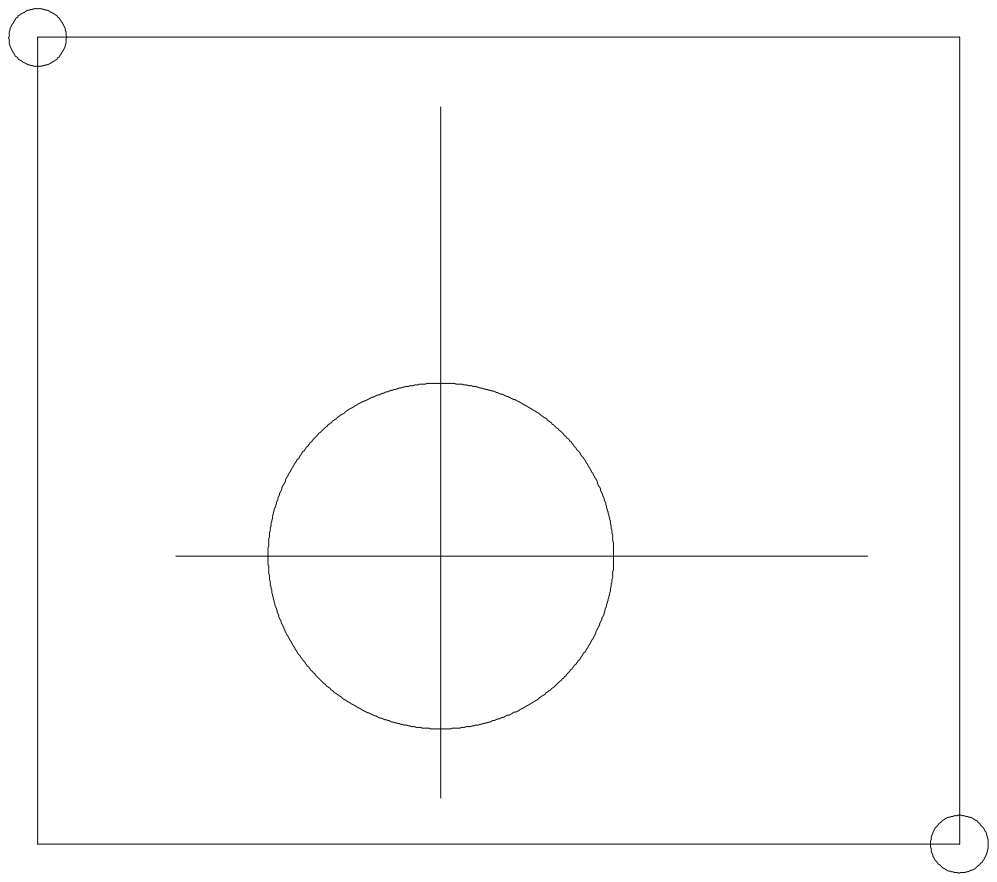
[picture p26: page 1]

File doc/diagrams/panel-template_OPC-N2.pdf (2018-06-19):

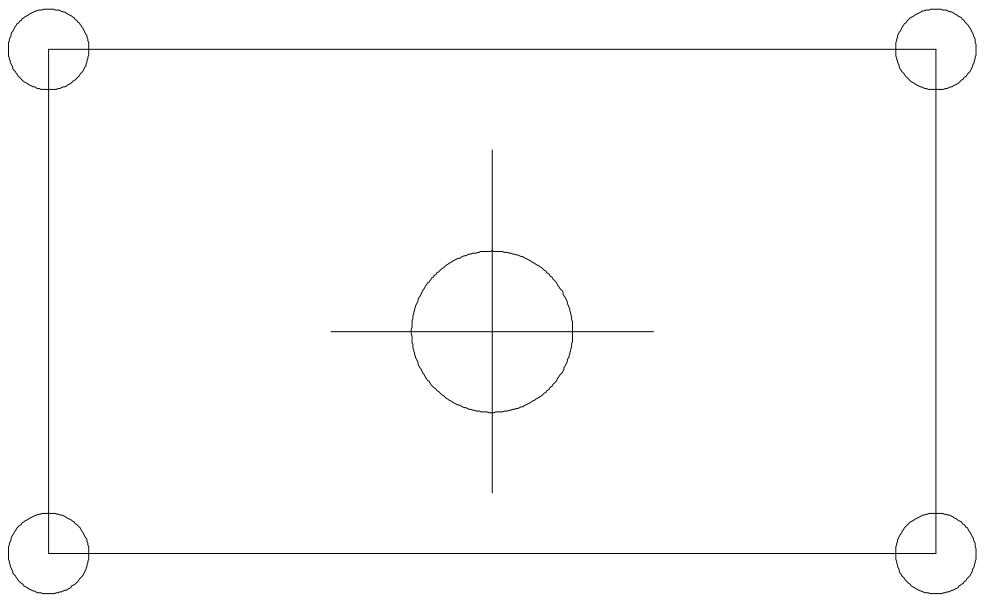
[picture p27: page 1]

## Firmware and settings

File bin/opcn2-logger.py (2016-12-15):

#!/usr/bin/python2
#
# Acquire data from OPC-N2
#
# Patrick O'Keeffe <pokeeffe@wsu.edu>
# Laboratory for Atmospheric Research at Washington State University

from __future__ import print_function

import os, os.path as osp
import time
import json
import logging
from logging.handlers import TimedRotatingFileHandler

import spidev
from opc import OPCN2

#### read config file
import ConfigParser as configparser
c = configparser.ConfigParser()
c.read('/etc/wsn/opcn2-logger.conf')

interval = c.getint('main', 'interval')
log_dir = c.get('logging', 'log_dir')
log_file = c.get('logging', 'log_file')
#######################################

#### logging setup
try:
    os.makedirs(log_dir)
except OSError:
    if not osp.isdir(log_dir):
        raise

tsfmt = '%Y-%m-%d %H:%M:%S'
jsonfmt = '{"%(asctime)s": %(message)s}'
log_fmt = logging.Formatter(jsonfmt,
                            datefmt=tsfmt)
log_file = TimedRotatingFileHandler(osp.join(log_dir, log_file),
                                    when='D', interval=30)
log_file.setFormatter(log_fmt)
log_file.suffix = '%Y-%m-%d.jsonl'
log = logging.getLogger(__name__)
log.setLevel(logging.INFO)
log.addHandler(log_file)

# for debugging
#log.addHandler(logging.StreamHandler())

# for urbanova
rundir = '/run/aqnet/opcn2/'
try:
    os.makedirs(rundir)
except OSError:
    if not osp.isdir(rundir):
        raise

spi = spidev.SpiDev()
spi.open(0,0)
spi.mode = 1
spi.max_speed_hz = 500000
opc = OPCN2(spi)
opc.on()

import atexit
@atexit.register
def cleanup():
    opc.off()


while True:
    try:
        data = opc.histogram()
        now = time.time()

        jsondata = {}
        for k,v in data.items():
            clean_name = k.replace(' ','_')
            string_val = 'NAN' if v is None else str(v)
            jsondata[clean_name] = string_val

            with open(rundir+clean_name, 'w') as f:
                f.write(string_val)

        # monthly-rotated flat json files
        log.info(json.dumps(data))

        time.sleep(interval)
    except (KeyboardInterrupt, SystemExit):
        opc.off()
        raise
    except:
        time.sleep(15)
        pass

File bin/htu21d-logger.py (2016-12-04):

#!/usr/bin/python2
#
# Acquire temperature/pressure data from HTU21D and do stuff
#
# Patrick O'Keeffe <pokeeffe@wsu.edu>
# Laboratory for Atmospheric Research at Washington State University

from __future__ import print_function

import os, os.path as osp
import time
import logging
from logging.handlers import TimedRotatingFileHandler

import sys
sys.path.append('/home/pi/weather-station')
from HTU21D import HTU21D
htu = HTU21D()

#### read config file
import ConfigParser as configparser
c = configparser.ConfigParser()
c.read('/etc/wsn/htu21d-logger.conf')

interval = c.getint('main', 'interval')
log_dir = c.get('logging', 'log_dir')
log_file = c.get('logging', 'log_file')
#######################################


#### logging setup
try:
    os.makedirs(log_dir)
except OSError:
    if not osp.isdir(log_dir):
        raise

# HINT alt. solution to http://stackoveflow.com/a/27858760
# XXXX does not handle partial-hour UTC offsets
#tzstr = '{:+03d}00'.format(-time.timezone/3600)
tsfmt = '%Y-%m-%dT%H:%M:%S'#+tzstr

log_fmt = logging.Formatter('%(asctime)s\t%(message)s',
                            datefmt=tsfmt)
log_file = TimedRotatingFileHandler(osp.join(log_dir, log_file),
                                    when='D', interval=30)
log_file.setFormatter(log_fmt)
log_file.suffix = '%Y-%m-%d.tsv'
log = logging.getLogger(__name__)
log.setLevel(logging.INFO)
log.addHandler(log_file)

# for urbanova
rundir = '/run/aqnet/htu21d'
run_T = os.path.join(rundir, 'T')
run_RH = os.path.join(rundir, 'RH')
try:
    os.makedirs(rundir)
except OSError:
    if not osp.isdir(rundir):
        raise


while True:
    try:
        T = htu.read_temperature()
        RH = htu.read_humidity()
        now = time.time()

        # rotating TSV files
        log.info('\t'.join(['{:0.2f}'.format(T),
                            '{:0.1f}'.format(RH)]))

        # for journalctl logs
        print('{{"T": {0:0.2f}, "RH": {1:0.1f}}}'.format(T, RH))

        # for Itron Riva
        with open(run_T, 'w') as f:
            f.write('{:0.2f}'.format(T))
        with open(run_RH, 'w') as f:
            f.write('{:0.2f}'.format(RH))

        time.sleep(interval)
    except (KeyboardInterrupt, SystemExit):
        raise
    except:
        time.sleep(15)
        pass

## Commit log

2016-11-01 Add RH/T sensor HTU21DF
2016-11-01 Start prototype script at boot
2016-11-01 Turn dust sensor off at shutdown
2016-12-04 Add K30 logging service
    lifted from IAQ wireless sensors project
2016-12-04 Add BMP280 logging service
    lifted from IAQ wireless sensor nodes, with modifications
2016-12-04 FIX: use consistent case in scalar names
    [k30-logger.py]
2016-12-04 FIX: standardize on 30 day log rotation
    [htu21d-logger.py, k30-logger.py]
2016-12-15 Fixup OPC-N2 logging to use JSON Lines format
    [opcn2-logger.py]
2016-12-15 TST: update sample freq and log file names for soak test #2
2018-06-19 DOC: add build notes
    [panel-layout_HTU21DF.dxf, panel-layout_K30.dxf, panel-layout_OPC-N2.dxf]
2018-06-26 Check-in testing data sets
    [SOAK2-PM10_001.csv, SOAK2-PM10_002.csv, SOAK2-PM10_003.csv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]
2018-06-26 Add notes from Itron cloud integration
    [data-schema.xlsx]
2018-07-24 FIX: update wiring diagram with correct pin layouts
    OPC-N2 and K30 had some swapped pins
2018-07-24 Reorganize directory structure
    [data-schema.xlsx, panel-layout_HTU21DF.dxf, panel-layout_K30.dxf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]
2018-07-24 Update wiring diagrams to current status
